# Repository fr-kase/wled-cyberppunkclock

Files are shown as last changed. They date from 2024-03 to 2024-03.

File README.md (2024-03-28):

# Welcome to my project, Cyberpunk Clock
It's my first project, so please be kind :)

# Results
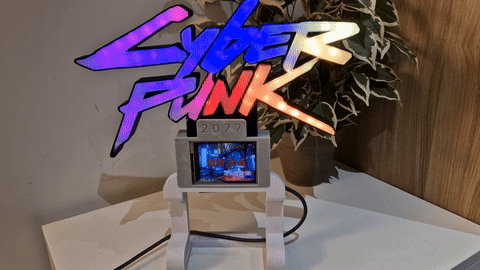
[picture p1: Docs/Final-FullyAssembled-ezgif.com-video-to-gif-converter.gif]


First thing, the final design and functionalities : 
- Amazing Led CyberPunk Logo based on the wonderful project WLED (with interface and a lot of things)
- Screen to see time, date, and if you have sensor temperature and humidity
- Touch screen to switch off the led

# Prerequisite & Materials
Skills : 
- Patience
- A little bit of programming
- Electronic: you need to know how to solder

Materials:
- A 3D printer  
- Electronic stuff like solder & co  
- A TFT ili9341 with touch capacity. I used the fantastic [TFT_eSPI library](https://github.com/Bodmer/TFT_eSPI/); a lot of other screens are compatible (check on the project)  
- A ESP, at the beginning, I used an ESP8266, but due to a lack of memory, I switched to an ESP32 with PS Ram; in my case, it's an ESP32-S2 mini (but there is a lot of ESP32)  
- An LED strip compatible with [WLED](https://github.com/Aircoookie/WLED) (check the project); in my case I bought a smaller LED WS2812B with only a 5 mm large
- Optional, a BME280 sensor

Sotfware:
- Visual Studio Code
- Platform.io plugin [check the guide from Wled project](https://kno.wled.ge/advanced/compiling-wled/)
- copy the directory "CyberpunkClock_v2" in the "usermod" directory
- copy the "platformio_override.ini" on the root (change the name for ESP8266)
- add in "wled00/usermods_list.cpp" two blocks
First just before "void registerUsermods()"
```
#ifdef USERMOD_CYBERPUNKCLOCK
#include "../usermods/CyberpunkClock_v2/cpc_v2.h"
#endif
```
Second at the end of file just before the "}"
```
  #ifdef USERMOD_CYBERPUNKCLOCK
  usermods.add(new CPC());
  #endif
```
I have got some errors during the compilation, in the BME280 usermod on the version 0.14 stable release a this moment
To fix that, I changed from
```
  uint8_t  TemperatureDecimals = 0;  // Number of decimal places in published temperaure values
  uint8_t  HumidityDecimals = 0;    // Number of decimal places in published humidity values
  uint8_t  PressureDecimals = 0;    // Number of decimal places in published pressure values
```
to
```
  uint  TemperatureDecimals = 0;  // Number of decimal places in published temperaure values
  uint  HumidityDecimals = 0;    // Number of decimal places in published humidity values
  uint  PressureDecimals = 0;    // Number of decimal places in published pressure values
```
And on JPEGDecoder.h
From 
```
  #if defined (ARDUINO_ARCH_ESP8266) || defined (ESP32)
    #define LOAD_FLASH_FS
    #include <pgmspace.h>
    #include <FS.h>
    #include <LittleFS.h>
    #define SPIFFS LittleFS
```
To
```
  #if defined (ARDUINO_ARCH_ESP8266) || defined (ESP32)
    #define LOAD_FLASH_FS
    #include <pgmspace.h>
    #include <FS.h>
    #include <LittleFS.h>
//    #define SPIFFS LittleFS
```
I tried on the pre-release version 0.15.0-b1 and the compilation doesn't work ...  
Because I forgot re-install "Node.js" see [the doc](https://kno.wled.ge/advanced/compiling-wled/)   
So after it works like a charm

# Instruction
## CyberPunk Logo
I started with the CyberPunk logo. This is [the link to the STL files](https://www.thingiverse.com/thing:4679493/files), and I read how other people have done the wiring.   
For the 3D print, I used default settings; for the case, a classic black PLA, and for the top, I used a semi-transparent PETG (because it was in my stock).  
The soldering of all LEDs is a big job and a little bit tricky; in my case, I had done a small part outside of the logo and made the connection when it was easy.  
I've also tested each time with a default WLED installation on my ESP8266 (it was before my switch to ESP32) to see if the LEDs are correctly connected.  
To resume, it was a little bit boring, but in the end, when you try different effects, you've got a first wahoo effect  

## The Clock
At the beginning, I started on a classical ESP8266, for the conenction you can use this:
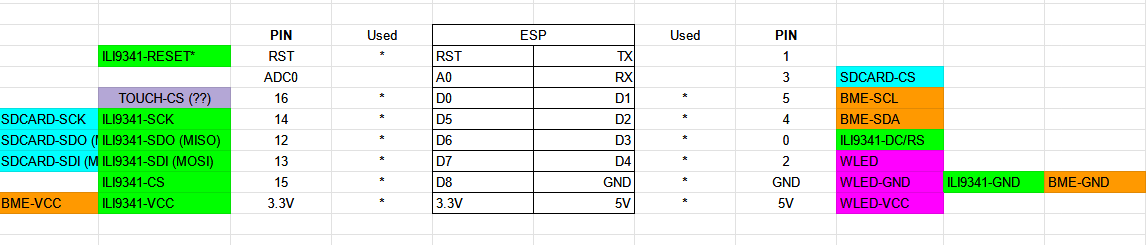
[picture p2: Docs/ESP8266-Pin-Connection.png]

However, when I used the TFT and Wled library, the memory was not enough to handle the background image on the "minute" display.  
I already use workaround in my code to avoid too many ressource, like load background image on the change of hour, so the "hour" isn't redraw.  
Perhaps, with more memory optimization, in my module and TFT and WLED project it's possible, but to be honest C++ is not my job just an hobbie.  
So long story short, if you have an ESP8266 you can use this module, but you will have a black background on the minute.  
If you have ESP32, with PS Ram, let's go  
Wiring on ESP32 S2 Mini  
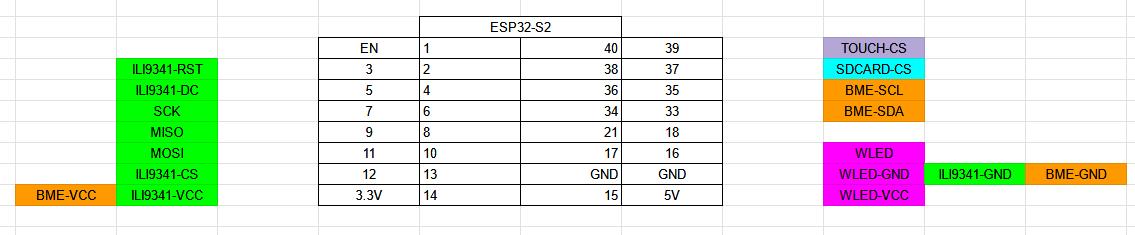
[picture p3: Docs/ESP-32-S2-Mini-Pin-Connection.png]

In my module, I used an another mod V2, thanks to [BME280_v2](https://github.com/Aircoookie/WLED/tree/main/usermods/BME280_v2) who provide function to get temparuture and other stuff  
After the wiring, I created a box for the clock with hole for USB, Pin to connect leg and big hole for the SD card.
My design is on OnShape, so if you want to remix, feel free.  
[Bottom](STL/CPC%20-%20Bottom.stl)   
[TOP](STL/CPC%20-%20Top.stl)   
[Link to CyberPunk Box](https://cad.onshape.com/documents/0ec2d05544ebf5b75362955c/w/2196f995b413a02e7a25c0e7/e/7b50c2d1ddb9066b0d95971f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)

## The Support
My idea is to integrate all this into a single object, but I like module parts.  
Yes, I know I have a 3D printer, so I could print all in a single, but I prefer to make different modules.  
And yes, I use glue between each part (from a 3D printer man it's could be horrible)  
But, by this way, you can modify all parts as you need.  
The mount between the clock and the logo  
[Mount](STL/CPC-Mount.stl)   
[Link to the mount](https://cad.onshape.com/documents/36fdbed2e2aa1ef3eded8675/w/fec956f36eaeb1502a5425e6/e/0c0e220b4aa753bca2f42ea8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)   

For the desgign, on the support I tried to keep an cyberpunk aspect (with a "2" profile)  
[Support](STL/CPC-Support.stl)   
[Link to the support](https://cad.onshape.com/documents/31070edaba85cf5046969ab0/w/2220fcad144101c9cb095c4e/e/76bb540df0e3aaddd11e8a31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)

## The SD Card
It's straightforward, you need to put your images at the root of the SD card and the name must be : background-XX.jpg (XX = hour)  
Like : "background-07.jpg".  
I suggest to resize to 320x240 pixels, but I guess if not the image will centered.   
Another limit, it's only JPG files   
Or can use directly images from the SD folder, as you wish:)  

# Story
This project is started, from my interests. 
* I love learn new thing (or relearn like the C++)
* The Cyberpunk univers (I read a lot of SF books, and the Cyberpunk 2077 from CD Projekt game is amazing)
* I've a 3D printer
* And last but not list for the fun

## The background
## Wiring Leds phase on the Logo
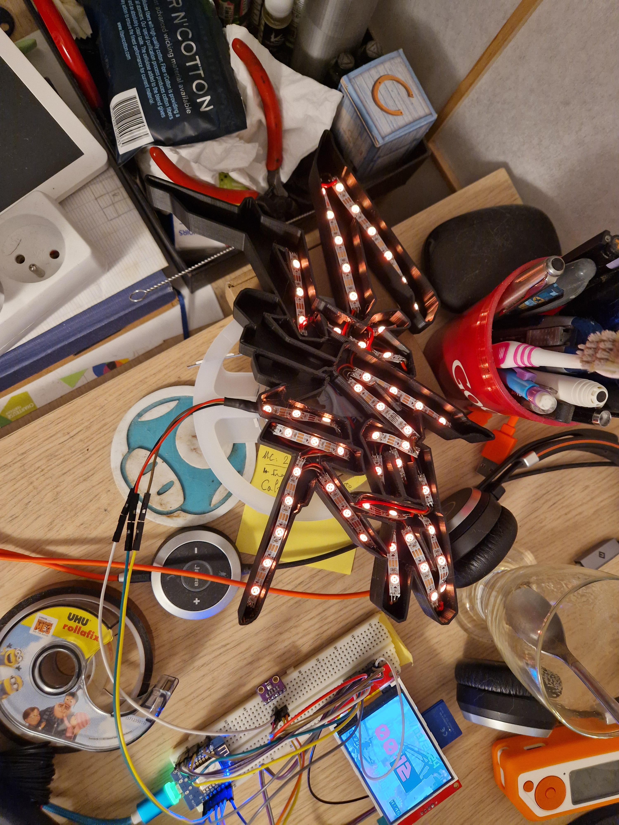
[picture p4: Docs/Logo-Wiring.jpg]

As you can see, it's a mess ;-)  
On the ESP8266, it's work  
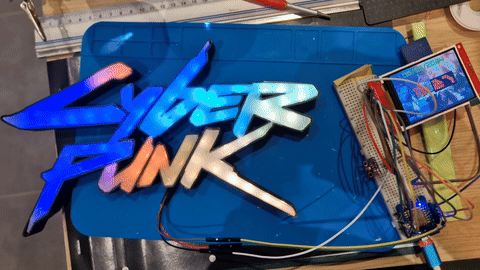
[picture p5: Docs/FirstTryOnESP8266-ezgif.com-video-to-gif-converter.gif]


On ESP32 S2 Mini
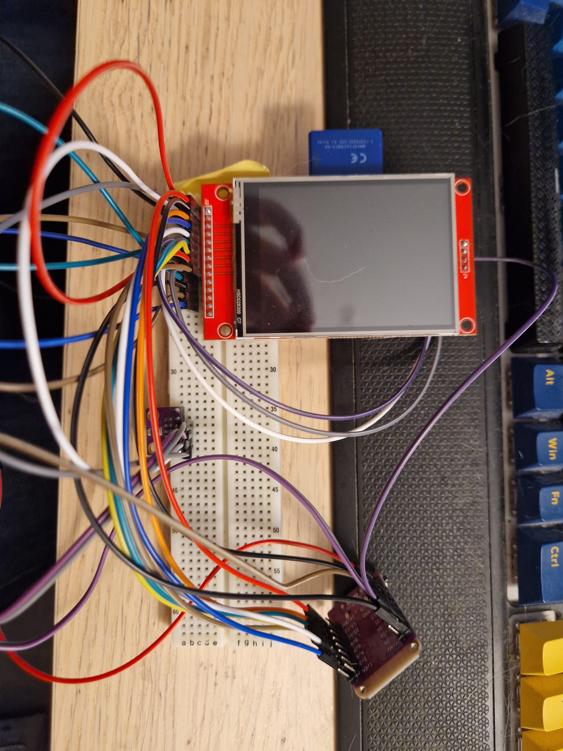
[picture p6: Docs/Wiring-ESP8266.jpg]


The final mount
Front 
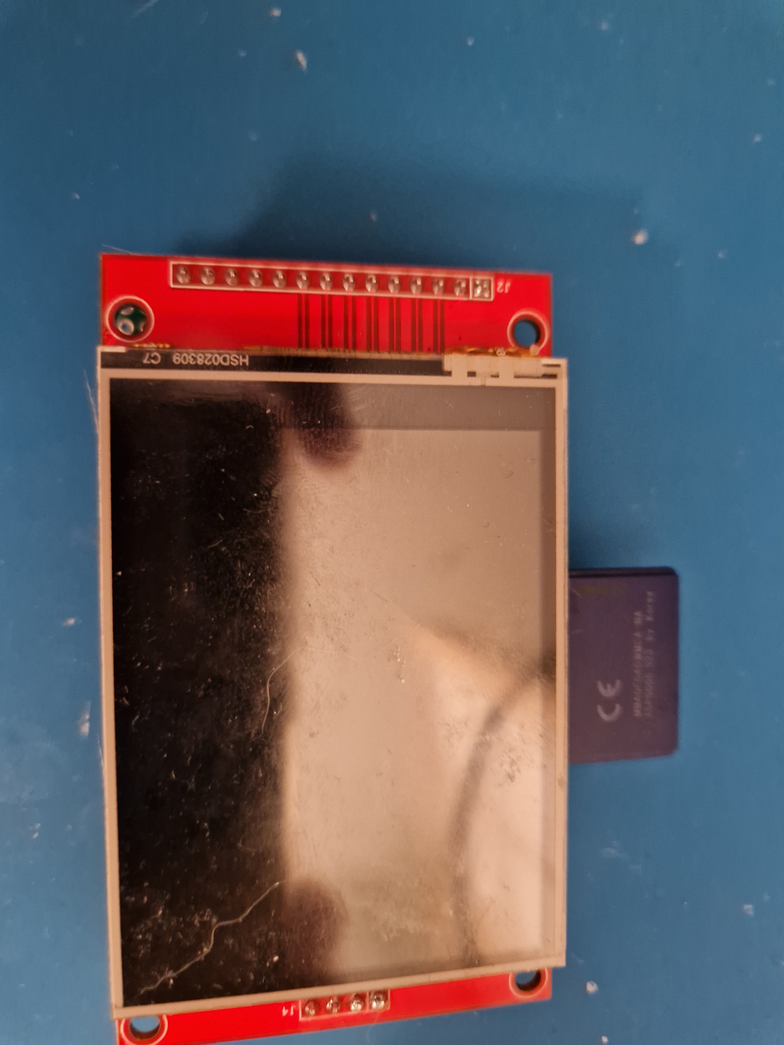
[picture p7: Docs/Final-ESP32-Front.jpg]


Back at the start  
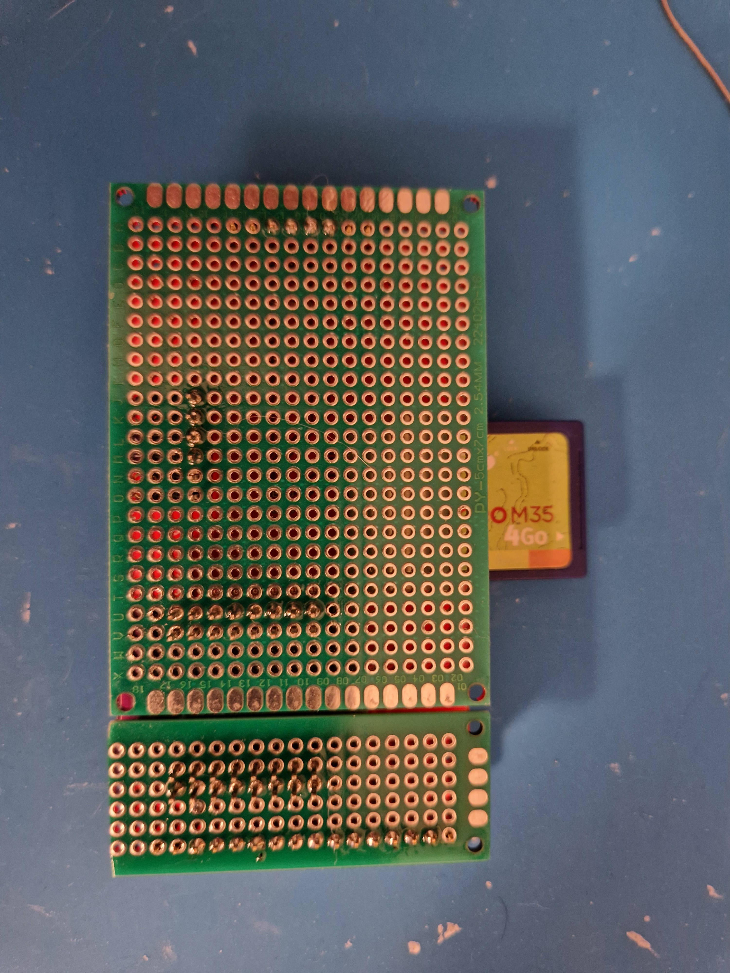
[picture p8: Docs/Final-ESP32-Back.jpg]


Back with modules  
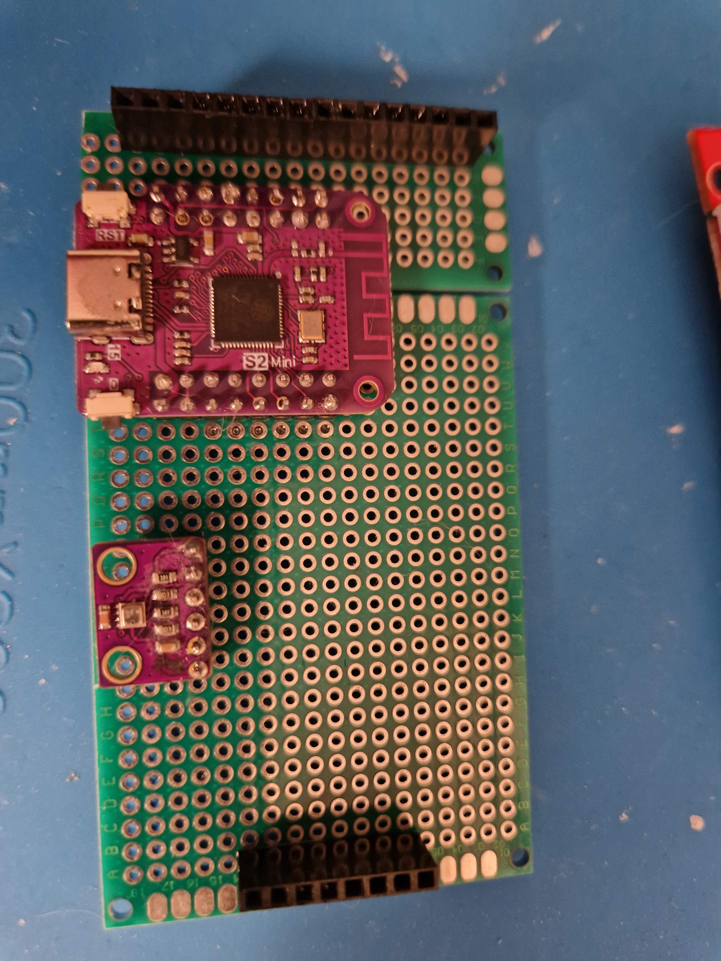
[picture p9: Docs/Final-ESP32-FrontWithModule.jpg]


The TFT with touch pin solder
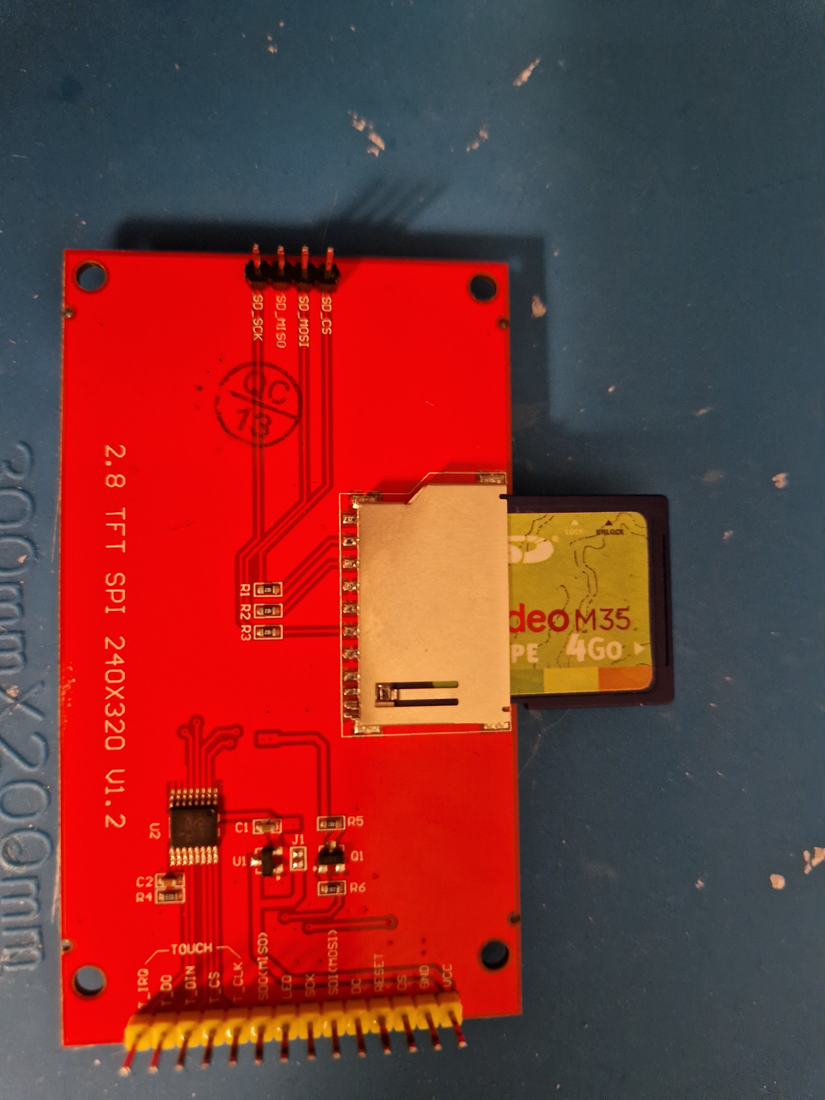
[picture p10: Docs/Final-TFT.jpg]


The sandwich  
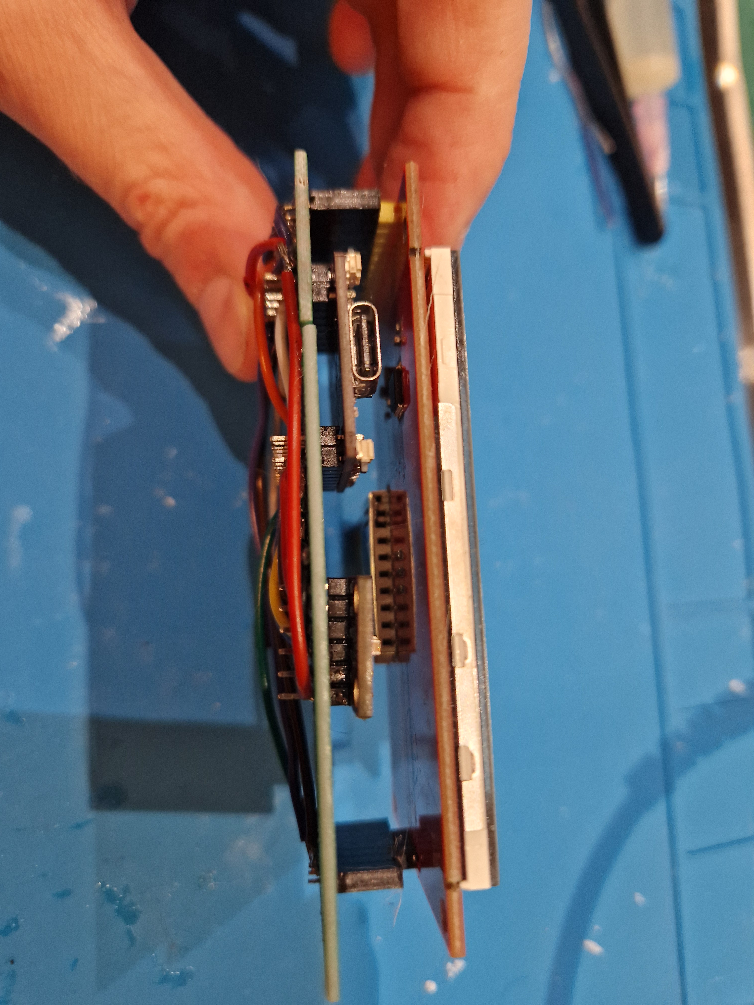
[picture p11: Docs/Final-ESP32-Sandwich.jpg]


Back with the wires  
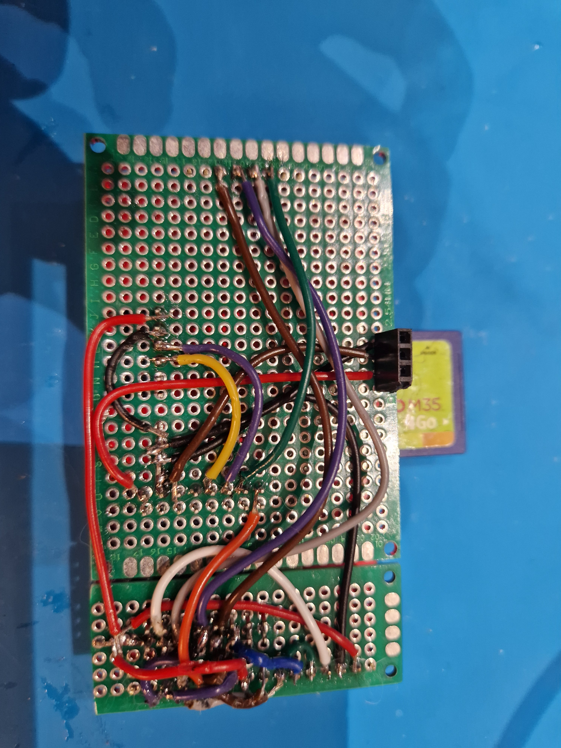
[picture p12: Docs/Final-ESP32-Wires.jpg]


Test with the touch  


The Mount
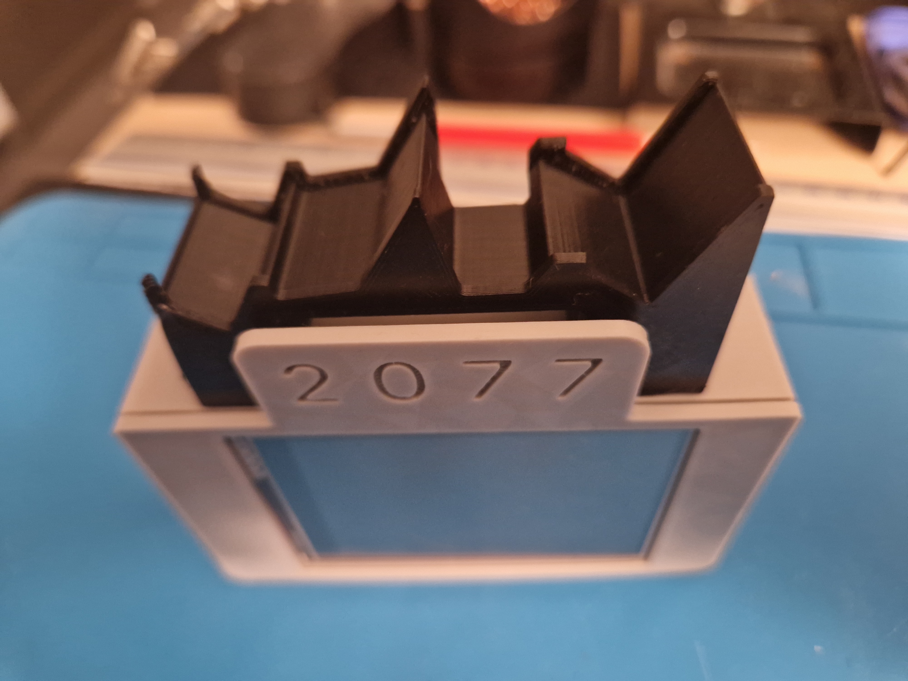
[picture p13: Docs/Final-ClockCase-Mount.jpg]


The Mount with the Logo
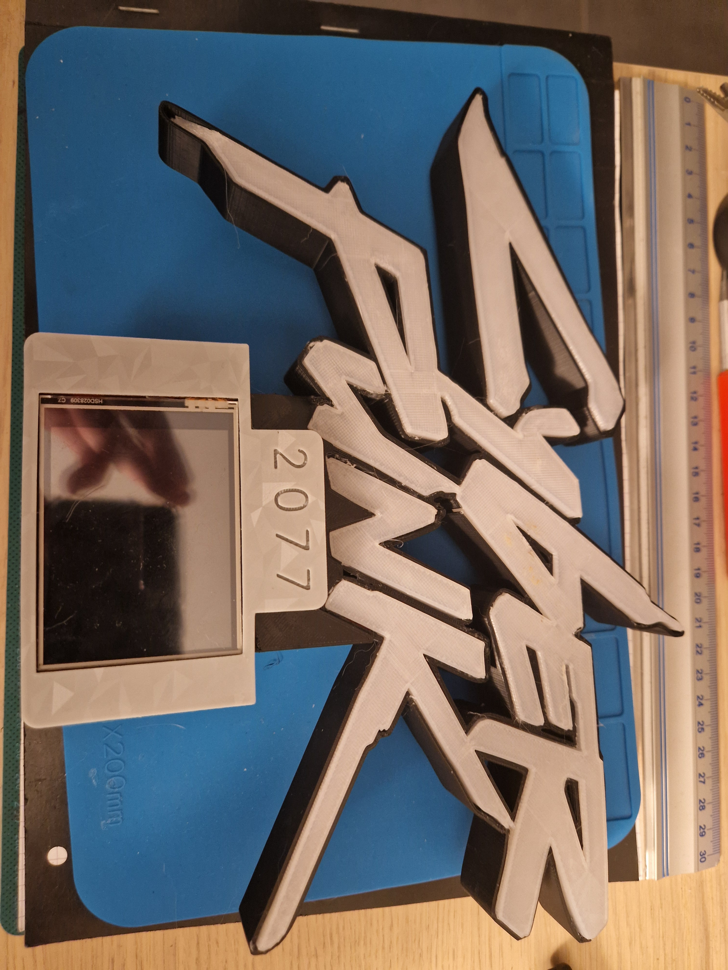
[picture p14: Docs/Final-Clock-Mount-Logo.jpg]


The back 
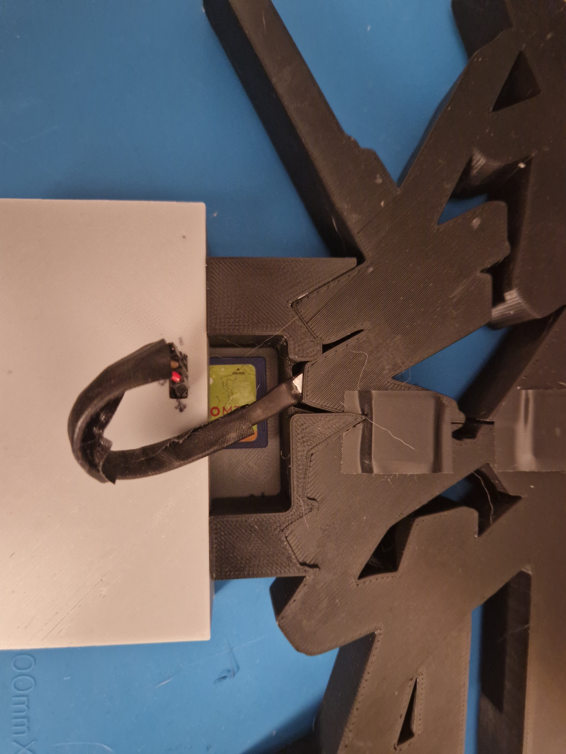
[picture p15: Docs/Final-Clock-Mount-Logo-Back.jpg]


The suppot Print
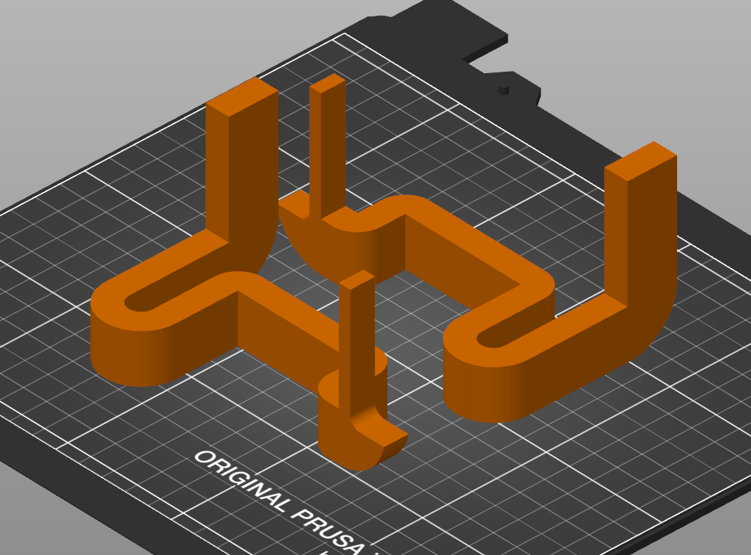
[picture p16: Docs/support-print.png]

(To avoid too many support)

The support
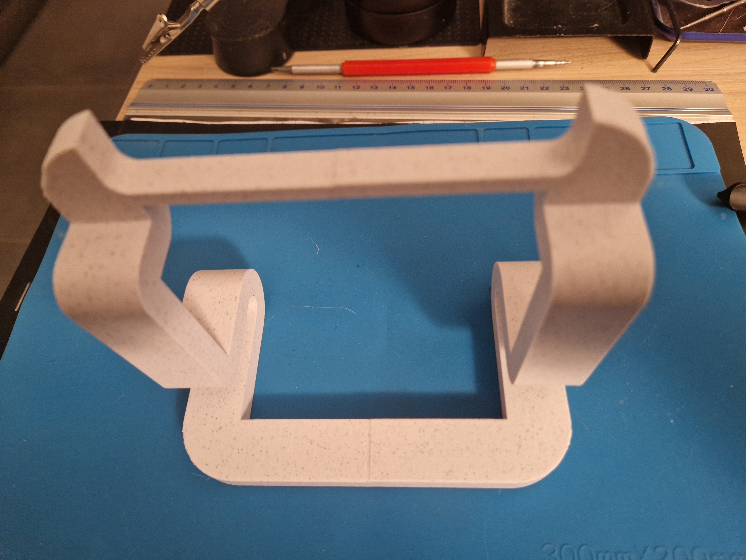
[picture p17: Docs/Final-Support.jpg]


The support side
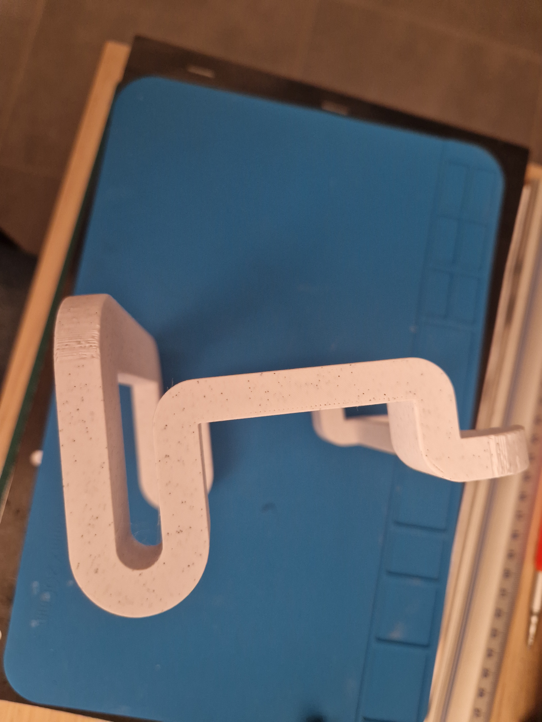
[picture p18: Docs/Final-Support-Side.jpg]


# Credits
Thanks to CD Projekt for the Cyber Punk 2077 game (and all trademarks for us).  
Thanks to Mr. Josef Prusa for the 3D printer. For making dreams a reality.  
Thanks to the community from Wled on the Discord (I asked a question less than 2 minutes after I've got the perfect answer)  
Thanks to the creator of the BME280_v2  
Thanks to OnShape for this 3D editor  
Sorry if I miss a trademark or copyright, but I'm not a lawyer and I hope this project is only to learn something

Images comes from :
https://www.flickr.com/photos/stefans02/51039796903
https://www.deviantart.com/favorisxp/art/Cyberpunk-2077-V-Night-City-animated-wallpaper-1017676737
https://www.deviantart.com/favorisxp/art/Cyberpunk-2077-Ultimate-Edition-animated-wallpaper-1019620294
https://www.deviantart.com/rs-eu/art/CYBERPUNK-2077-Panam-V2-919674818
https://www.deviantart.com/crazyjackaljones/art/Cyberpunk-2077-Night-City-Day-762575039
https://www.deviantart.com/pixeljeff/art/Cyberpunk-2077-863580549
https://www.deviantart.com/starl0rd84/art/Night-City-Cyberpunk-2077-849046615
https://www.deviantart.com/1n-stereo/art/Cyberpunk-2077-365263922
https://www.deviantart.com/tatteredlurker/art/Bladepunk-Legacy-2077-824967314
https://www.deviantart.com/rocksdanister/art/Night-City-Cyberpunk-840875135
https://www.deviantart.com/bartgru89/art/Cyberpunk-2077-Night-City-886209657
https://www.deviantart.com/bartgru89/art/Cyberpunk-2077-Night-City-886209657
https://www.deviantart.com/swampgassed/art/Night-City-Cyberpunk-2077-864142424
https://www.deviantart.com/gregouny/art/Cyberpunk-2077-Night-City-867133443
https://www.deviantart.com/niles1999/art/Cyberpunk-2077-FanArt-800091799
https://www.deviantart.com/outadimes/art/Judy-Alvarez-935987411
https://www.deviantart.com/swampgassed/art/Night-City-Cyberpunk-2077-864142714

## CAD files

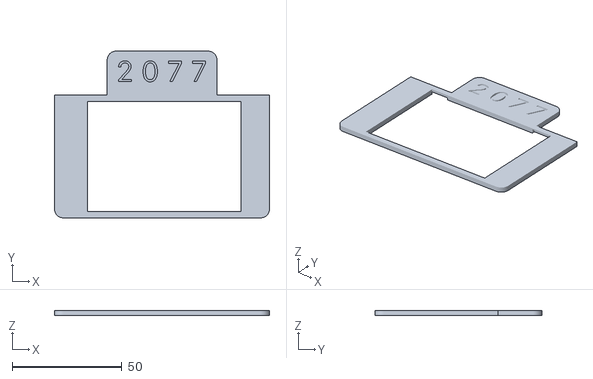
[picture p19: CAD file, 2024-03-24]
STL/CPC - Top.stl
98.0 x 76.0 x 2.50

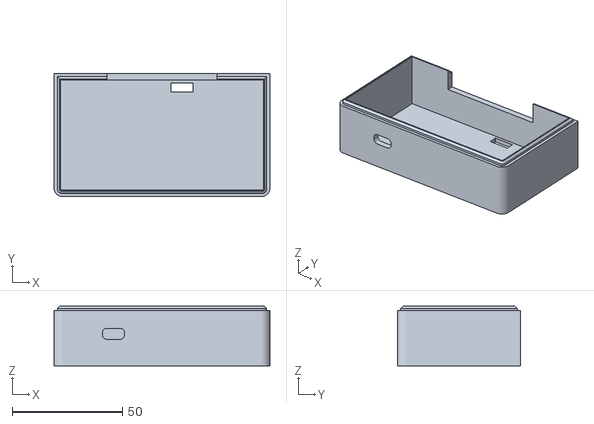
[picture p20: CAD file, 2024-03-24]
STL/CPC - Bottom.stl
98.0 x 56.0 x 27.0

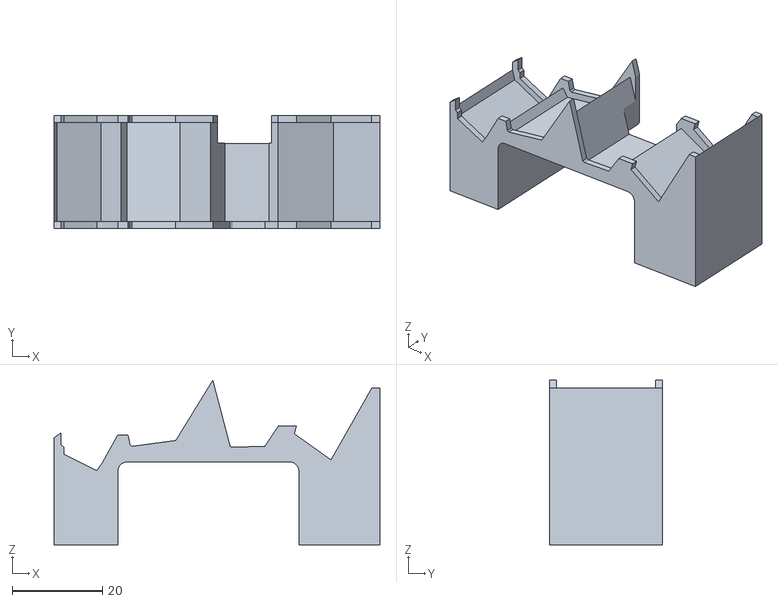
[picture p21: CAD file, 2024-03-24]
STL/CPC-Mount.stl
72.1 x 25.0 x 36.5

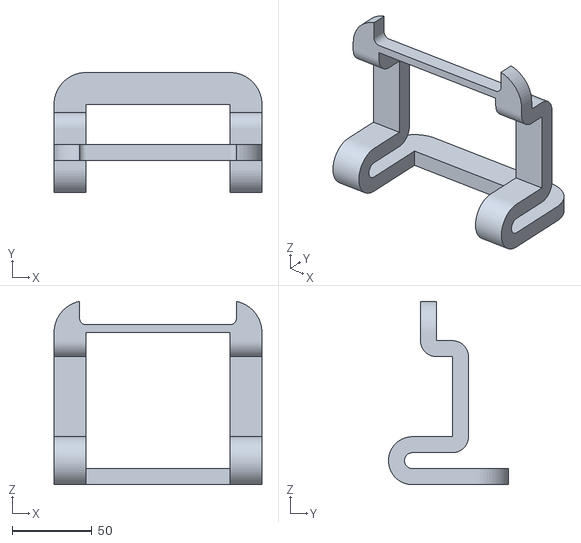
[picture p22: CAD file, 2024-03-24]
STL/CPC-Support.stl
130.0 x 75.0 x 114.6

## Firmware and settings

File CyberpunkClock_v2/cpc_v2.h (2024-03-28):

#pragma once

#include "wled.h"

//FOR TFT Settings COPY your OWN "User_Setup.h"

#include <FS.h>
#include <SD.h>
#include <JPEGDecoder.h>
#include <TFT_eSPI.h> // Hardware-specific library
#include <SPI.h>
#include <HardwareSerial.h>



//Smooth Fonts
#include "valorax64.h"
#include "Akashi32.h"
#include "Joystix16.h"


/*
 * Usermods allow you to add own functionality to WLED more easily
 * See: https://github.com/Aircoookie/WLED/wiki/Add-own-functionality
 * 
 * This is an example for a v2 usermod.
 * v2 usermods are class inheritance based and can (but don't have to) implement more functions, each of them is shown in this example.
 * Multiple v2 usermods can be added to one compilation easily.
 * 
 * Creating a usermod:
 * This file serves as an example. If you want to create a usermod, it is recommended to use usermod_v2_empty.h from the usermods folder as a template.
 * Please remember to rename the class and file to a descriptive name.
 * You may also use multiple .h and .cpp files.
 * 
 * Using a usermod:
 * 1. Copy the usermod into the sketch folder (same folder as wled00.ino)
 * 2. Register the usermod by adding #include "usermod_filename.h" in the top and registerUsermod(new MyUsermodClass()) in the bottom of usermods_list.cpp
 */
#define USERMOD_ID_CPC       69

#define SD_CS    37  // Chip select SD Card

#define BUILDTM_YEAR (\
    __DATE__[7] == '?' ? 1900 \
    : (((__DATE__[7] - '0') * 1000 ) \
    + (__DATE__[8] - '0') * 100 \
    + (__DATE__[9] - '0') * 10 \
    + __DATE__[10] - '0'))

#define BUILDTM_MONTH (\
    __DATE__ [2] == '?' ? 1 \
    : __DATE__ [2] == 'n' ? (__DATE__ [1] == 'a' ? 1 : 6) \
    : __DATE__ [2] == 'b' ? 2 \
    : __DATE__ [2] == 'r' ? (__DATE__ [0] == 'M' ? 3 : 4) \
    : __DATE__ [2] == 'y' ? 5 \
    : __DATE__ [2] == 'l' ? 7 \
    : __DATE__ [2] == 'g' ? 8 \
    : __DATE__ [2] == 'p' ? 9 \
    : __DATE__ [2] == 't' ? 10 \
    : __DATE__ [2] == 'v' ? 11 \
    : 12)

#define BUILDTM_DAY (\
    __DATE__[4] == '?' ? 1 \
    : ((__DATE__[4] == ' ' ? 0 : \
    ((__DATE__[4] - '0') * 10)) + __DATE__[5] - '0'))


//class name. Use something descriptive and leave the ": public Usermod" part :)
class CPC : public Usermod {

  private:
    // Private class members. You can declare variables and functions only accessible to your usermod here
    bool enabled = false;
    bool initDone = false;

    TFT_eSPI tft = TFT_eSPI();
    bool sdCardEnabled = false;

    int posXHourMiddle=0;
    
    int posXHourRight=0;
    int posXHourLeft=0;
    uint8_t middleCar=0;

    int posYDate=24;
    int posYHour=96;
    int posYBME=208;
    
    char minutesString[4];
    char BMEString [20];
    char BMEStringHum [20];
    byte currentBri;

    // FROM https://chrishewett.com/blog/true-rgb565-colour-picker/ use RGB565 

    String dateColor = "0x0320";
    String BMEColor = "0x3231";
    String timeColor = "0xA800";

    //If we don't have any informations from the current time
    //We retrieve the build time and after we will increment it.
    //Not the best way, so please enable NTP in WLED
    //static uint8_t conv2d(const char* p); // Forward declaration needed for IDE 1.6.x
    uint8_t hh = conv2d(__TIME__), mm = conv2d(__TIME__ + 3), ss = conv2d(__TIME__ + 6); // Get H, M, S from compile time

    //Internal variables to detect movement
    byte omm = 99, oss = 99, ohh=99;

    //If the ESP has enough memory we will use to have a transpancy effet when we update the "minute"
    uint16_t* screenContent = NULL;
    //To avoid refresh too frequently
    uint32_t targetTime = 0;                    // for next 1 second timeout
    
    //If you have a BME280 and enabled the usermod we will show temperature & humidity
    uint8_t humidity = 0;
    int temperature = 0;
    //Sometimes we need calibration
    int temperatureCorrection = 0;
    uint8_t humidityCorrection = 0;

    // The library defines the type "setup_t" as a struct
    setup_t user;
    
    //Check if the user mode BME280 is enabled and get a pointer to the instance
    #ifdef USERMOD_BME280
       UsermodBME280* BME;
    #endif

    // string that are used multiple time (this will save some flash memory)
    static const char _name[];
    static const char _enabled[];

    // any private methods should go here (non-inline method should be defined out of class)
    void publishMqtt(const char* state, bool retain = false); // example for publishing MQTT message
    
    // Function to extract numbers from compile time string
    static uint8_t conv2d(const char* p) {
      uint8_t v = 0;
      if ('0' <= *p && *p <= '9')
        v = *p - '0';
      return 10 * v + *++p - '0';
    }

    // LIBS
    //####################################################################################################
    // Draw a JPEG on the TFT, images will be cropped on the right/bottom sides if they do not fit
    //####################################################################################################
    // This function assumes xpos,ypos is a valid screen coordinate. For convenience images that do not
    // fit totally on the screen are cropped to the nearest MCU size and may leave right/bottom borders.
    void jpegRender(int xpos, int ypos) {

      //jpegInfo(); // Print information from the JPEG file (could comment this line out)

      uint16_t *pImg;
      uint16_t mcu_w = JpegDec.MCUWidth;
      uint16_t mcu_h = JpegDec.MCUHeight;
      uint32_t max_x = JpegDec.width;
      uint32_t max_y = JpegDec.height;

      bool swapBytes = tft.getSwapBytes();
      // I don't kwow why but on my ESP8266 I need to remove, however in my ESP32 it works so...
      #if defined(ESP32)
        tft.setSwapBytes(true);
      #endif
      
      // Jpeg images are draw as a set of image block (tiles) called Minimum Coding Units (MCUs)
      // Typically these MCUs are 16x16 pixel blocks
      // Determine the width and height of the right and bottom edge image blocks
      uint32_t min_w = jpg_min(mcu_w, max_x % mcu_w);
      uint32_t min_h = jpg_min(mcu_h, max_y % mcu_h);

      // save the current image block size
      uint32_t win_w = mcu_w;
      uint32_t win_h = mcu_h;

      // record the current time so we can measure how long it takes to draw an image
      //uint32_t drawTime = millis();

      // save the coordinate of the right and bottom edges to assist image cropping
      // to the screen size
      max_x += xpos;
      max_y += ypos;

      // Fetch data from the file, decode and display
      while (JpegDec.read()) {    // While there is more data in the file
        pImg = JpegDec.pImage ;   // Decode a MCU (Minimum Coding Unit, typically a 8x8 or 16x16 pixel block)

        // Calculate coordinates of top left corner of current MCU
        uint32_t mcu_x = JpegDec.MCUx * mcu_w + xpos;
        uint32_t mcu_y = JpegDec.MCUy * mcu_h + ypos;
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

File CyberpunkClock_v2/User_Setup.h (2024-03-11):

//                            USER DEFINED SETTINGS
//   Set driver type, fonts to be loaded, pins used and SPI control method etc
//
//   See the User_Setup_Select.h file if you wish to be able to define multiple
//   setups and then easily select which setup file is used by the compiler.
//
//   If this file is edited correctly then all the library example sketches should
//   run without the need to make any more changes for a particular hardware setup!
//   Note that some sketches are designed for a particular TFT pixel width/height

// User defined information reported by "Read_User_Setup" test & diagnostics example
//#define USER_SETUP_INFO "User_Setup"

// Define to disable all #warnings in library (can be put in User_Setup_Select.h)
//#define DISABLE_ALL_LIBRARY_WARNINGS

// ##################################################################################
//
// Section 1. Call up the right driver file and any options for it
//
// ##################################################################################

// Define STM32 to invoke optimised processor support (only for STM32)
//#define STM32

// Defining the STM32 board allows the library to optimise the performance
// for UNO compatible "MCUfriend" style shields
//#define NUCLEO_64_TFT
//#define NUCLEO_144_TFT

// STM32 8 bit parallel only:
// If STN32 Port A or B pins 0-7 are used for 8 bit parallel data bus bits 0-7
// then this will improve rendering performance by a factor of ~8x
//#define STM_PORTA_DATA_BUS
//#define STM_PORTB_DATA_BUS

// Tell the library to use parallel mode (otherwise SPI is assumed)
//#define TFT_PARALLEL_8_BIT
//#defined TFT_PARALLEL_16_BIT // **** 16 bit parallel ONLY for RP2040 processor ****

// Display type -  only define if RPi display
//#define RPI_DISPLAY_TYPE // 20MHz maximum SPI

// Only define one driver, the other ones must be commented out
#define ILI9341_DRIVER       // Generic driver for common displays
//#define ILI9341_2_DRIVER     // Alternative ILI9341 driver, see https://github.com/Bodmer/TFT_eSPI/issues/1172
//#define ST7735_DRIVER      // Define additional parameters below for this display
//#define ILI9163_DRIVER     // Define additional parameters below for this display
//#define S6D02A1_DRIVER
//#define RPI_ILI9486_DRIVER // 20MHz maximum SPI
//#define HX8357D_DRIVER
//#define ILI9481_DRIVER
//#define ILI9486_DRIVER
//#define ILI9488_DRIVER     // WARNING: Do not connect ILI9488 display SDO to MISO if other devices share the SPI bus (TFT SDO does NOT tristate when CS is high)
//#define ST7789_DRIVER      // Full configuration option, define additional parameters below for this display
//#define ST7789_2_DRIVER    // Minimal configuration option, define additional parameters below for this display
//#define R61581_DRIVER
//#define RM68140_DRIVER
//#define ST7796_DRIVER
//#define SSD1351_DRIVER
//#define SSD1963_480_DRIVER
//#define SSD1963_800_DRIVER
//#define SSD1963_800ALT_DRIVER
//#define ILI9225_DRIVER
//#define GC9A01_DRIVER

// Some displays support SPI reads via the MISO pin, other displays have a single
// bi-directional SDA pin and the library will try to read this via the MOSI line.
// To use the SDA line for reading data from the TFT uncomment the following line:

// #define TFT_SDA_READ      // This option is for ESP32 ONLY, tested with ST7789 and GC9A01 display only

// For ST7735, ST7789 and ILI9341 ONLY, define the colour order IF the blue and red are swapped on your display
// Try ONE option at a time to find the correct colour order for your display

//  #define TFT_RGB_ORDER TFT_RGB  // Colour order Red-Green-Blue
//  #define TFT_RGB_ORDER TFT_BGR  // Colour order Blue-Green-Red

// For M5Stack ESP32 module with integrated ILI9341 display ONLY, remove // in line below

// #define M5STACK

// For ST7789, ST7735, ILI9163 and GC9A01 ONLY, define the pixel width and height in portrait orientation
// #define TFT_WIDTH  80
// #define TFT_WIDTH  128
// #define TFT_WIDTH  172 // ST7789 172 x 320
// #define TFT_WIDTH  170 // ST7789 170 x 320
#define TFT_WIDTH  240 // ST7789 240 x 240 and 240 x 320
// #define TFT_HEIGHT 160
// #define TFT_HEIGHT 128
// #define TFT_HEIGHT 240 // ST7789 240 x 240
#define TFT_HEIGHT 320 // ST7789 240 x 320
// #define TFT_HEIGHT 240 // GC9A01 240 x 240

// For ST7735 ONLY, define the type of display, originally this was based on the
// colour of the tab on the screen protector film but this is not always true, so try
// out the different options below if the screen does not display graphics correctly,
// e.g. colours wrong, mirror images, or stray pixels at the edges.
// Comment out ALL BUT ONE of these options for a ST7735 display driver, save this
// this User_Setup file, then rebuild and upload the sketch to the board again:

// #define ST7735_INITB
// #define ST7735_GREENTAB
// #define ST7735_GREENTAB2
// #define ST7735_GREENTAB3
// #define ST7735_GREENTAB128    // For 128 x 128 display
// #define ST7735_GREENTAB160x80 // For 160 x 80 display (BGR, inverted, 26 offset)
// #define ST7735_ROBOTLCD       // For some RobotLCD arduino shields (128x160, BGR, https://docs.arduino.cc/retired/getting-started-guides/TFT)
// #define ST7735_REDTAB
// #define ST7735_BLACKTAB
// #define ST7735_REDTAB160x80   // For 160 x 80 display with 24 pixel offset

// If colours are inverted (white shows as black) then uncomment one of the next
// 2 lines try both options, one of the options should correct the inversion.

// #define TFT_INVERSION_ON
// #define TFT_INVERSION_OFF


// ##################################################################################
//
// Section 2. Define the pins that are used to interface with the display here
//
// ##################################################################################

// If a backlight control signal is available then define the TFT_BL pin in Section 2
// below. The backlight will be turned ON when tft.begin() is called, but the library
// needs to know if the LEDs are ON with the pin HIGH or LOW. If the LEDs are to be
// driven with a PWM signal or turned OFF/ON then this must be handled by the user
// sketch. e.g. with digitalWrite(TFT_BL, LOW);

// #define TFT_BL   32            // LED back-light control pin
// #define TFT_BACKLIGHT_ON HIGH  // Level to turn ON back-light (HIGH or LOW)
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

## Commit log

2024-03-11 For ESP32-S2-Mini
2024-03-11 Pin Connection
2024-03-11 ESP8266 Pin Connection
2024-03-28 Fix a little memory leak :)
    [cpc_v2.h]
2024-03-28 With the correct file
    [cpc_v2.h]
